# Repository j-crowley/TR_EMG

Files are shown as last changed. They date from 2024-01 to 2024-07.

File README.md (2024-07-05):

# TR_EMG
The Trans-radial EMG (TREMG) is a PCB designed to increase SNR for surface-level EMG electrodes which is then digitized and sent to a controller to drive a robotic prosthetic. This is for individuals with upper limb amputations at the trans-radial level. It enables users to regain dexterity and perform a wide range of tasks using a prosthetic hand. This repository includes the final design of the PCB for this project and does not include the code.

# Credits
Credits to the rest of the capstone team, including: ThaneGallo and coop-bennett.

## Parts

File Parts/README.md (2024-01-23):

# How to import
https://www.snapeda.com/about/import/#KiCad6

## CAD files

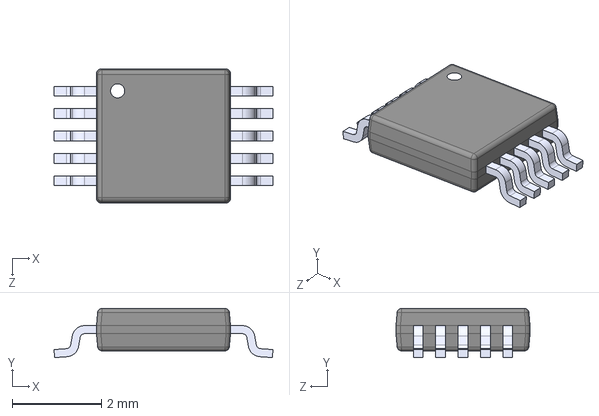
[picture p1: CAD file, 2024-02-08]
Parts/footprints/ADS1115IDGSR.step
4.90 x 1.10 x 3.00 mm

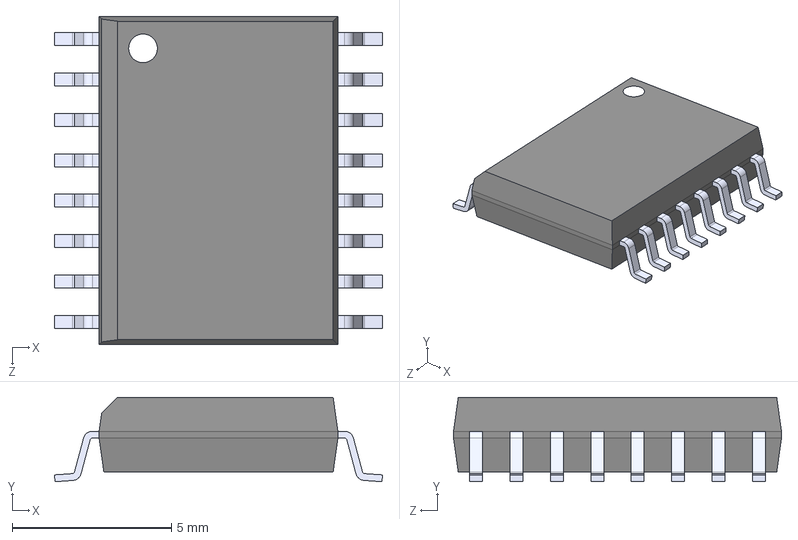
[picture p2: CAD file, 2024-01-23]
Parts/symbols/INA115BU/INA115BU.step
10.3 x 2.65 x 10.3 mm

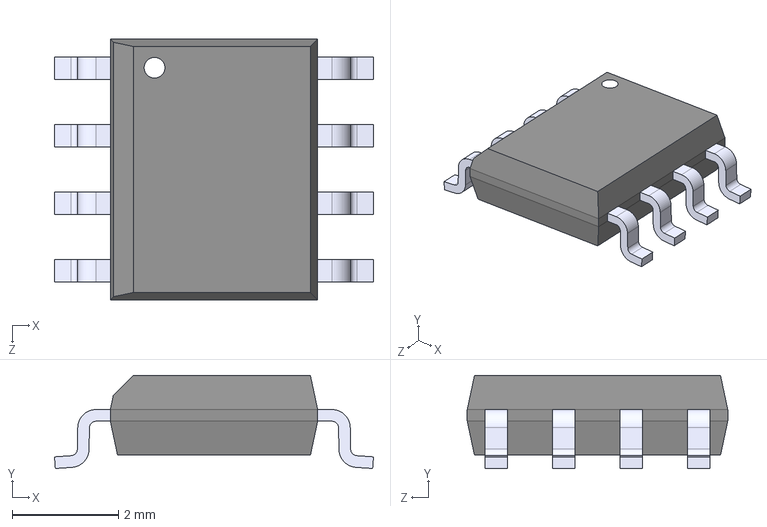
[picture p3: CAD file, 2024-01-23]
Parts/symbols/LM2904DR/LM2904DR.step
6.00 x 1.75 x 4.90 mm

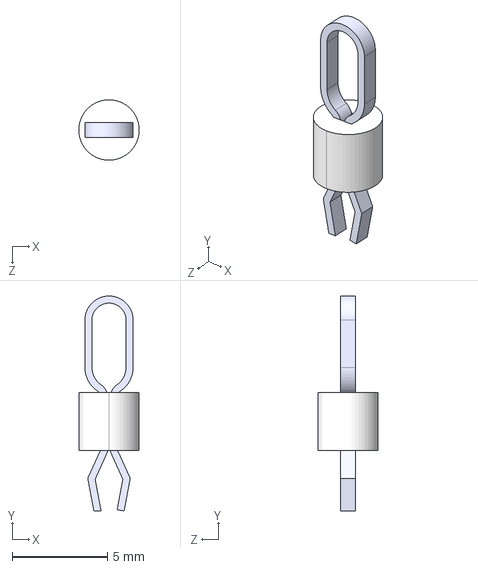
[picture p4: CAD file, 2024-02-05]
Parts/footprints/5012.step
3.17 x 11.3 x 3.17 mm

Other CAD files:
Parts/footprints/INA115BU.step
Parts/footprints/LM2904DR.step

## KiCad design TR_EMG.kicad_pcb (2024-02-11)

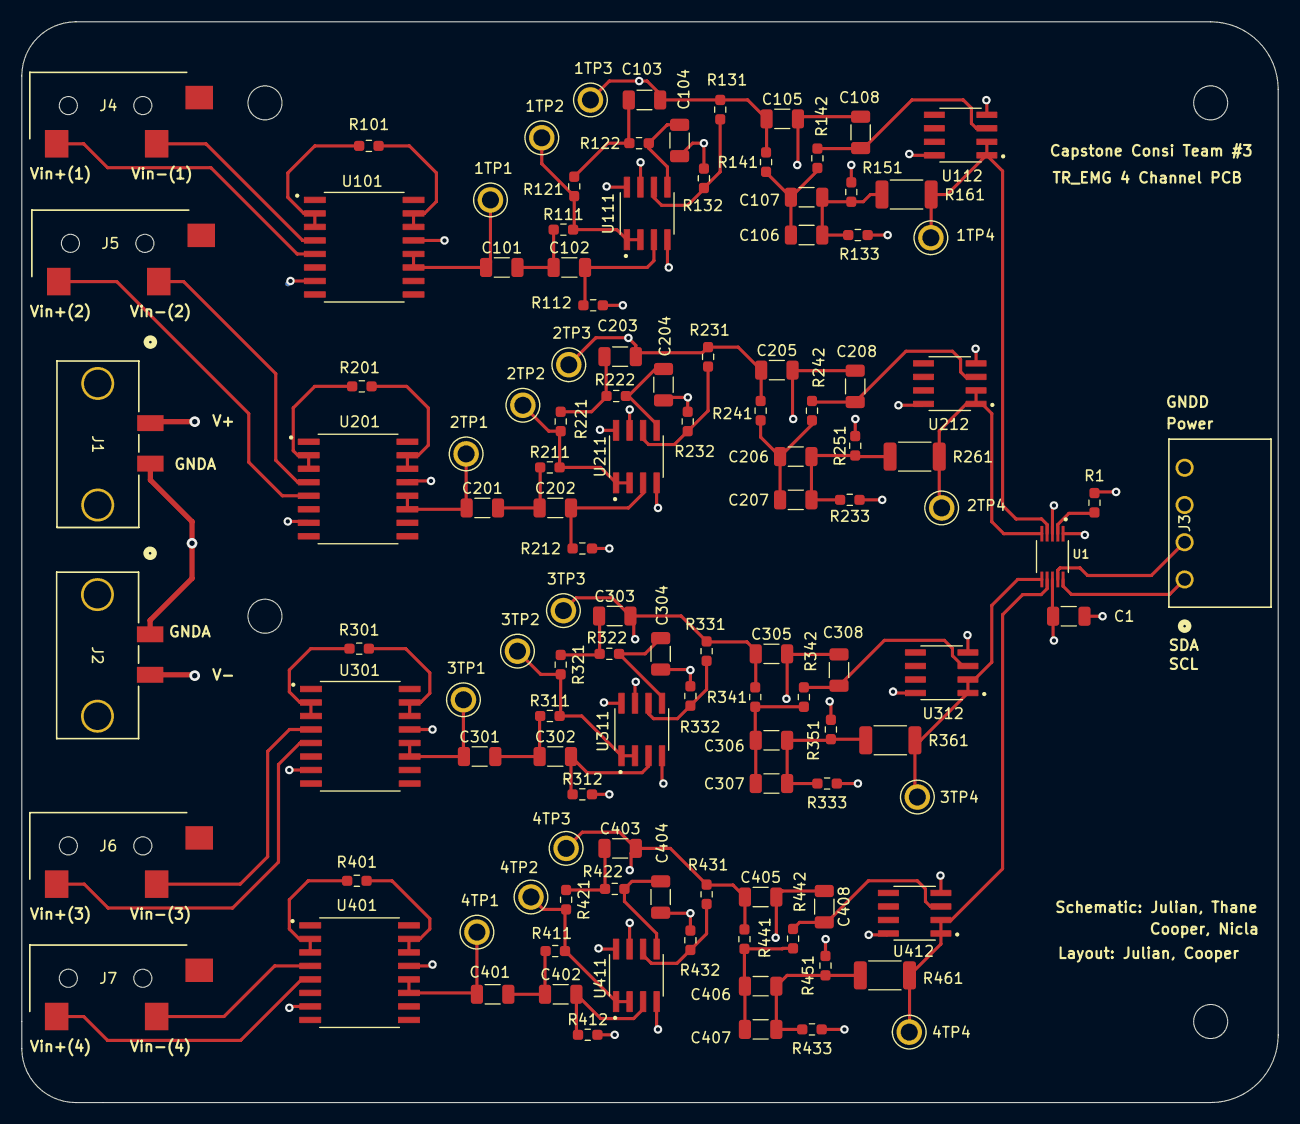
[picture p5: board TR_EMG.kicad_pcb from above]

Board: 4 copper layers, 118.1 x 101.6 mm, 118 parts (0 on the bottom side), 76 nets.

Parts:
1TP1, 1TP2, 1TP3, 1TP4, 2TP1, 2TP2, 2TP3, 2TP4, 3TP1, 3TP2, 3TP3, 3TP4, 4TP1, 4TP2, 4TP3, 4TP4: 5012; TP_5012
C1: 0.1 u; C_1206_3216Metric
C101, C102, C103, C104, C105, C106, C107, C108, C201, C202, C203, C204, C205, C206, C207, C208, C301, C302, C303, C304, C305, C306, C307, C308, C401, C402, C403, C404, C405, C406, C407, C408: 0.1u; C_1206_3216Metric
J1, J2: 1727230; CONN_1727230_PXC
J3: 1844236; CONN_1844236_PXC
J4, J5, J6, J7: MJ-3523-SMT-TR; CONN_MJ-3523_CUD_CtYrd
R1, R131, R132, R231, R232, R331, R332, R431, R432: 1k; R_0603_1608Metric_Pad0.98x0.95mm_HandSolder
R101, R201, R301, R401: 100; R_0603_1608Metric_Pad0.98x0.95mm_HandSolder
R111, R112, R211, R212, R311, R312, R411, R412: 330k; R_0603_1608Metric_Pad0.98x0.95mm_HandSolder
R121, R122, R221, R222, R321, R322, R421, R422: 3.3k; R_0603_1608Metric_Pad0.98x0.95mm_HandSolder
R133, R233, R333, R433: 100k; R_0603_1608Metric_Pad0.98x0.95mm_HandSolder
R141, R142, R241, R242, R341, R342, R441, R442: 26.7k; R_0603_1608Metric_Pad0.98x0.95mm_HandSolder
R151, R251, R351, R451: 13k; R_0603_1608Metric_Pad0.98x0.95mm_HandSolder
R161, R261, R361, R461: 150; R_2010_5025Metric
U1: ADS1115IDGSR; ADS-SOP50P490X110-10N
U101, U201, U301, U401: INA115BU; INA-SOIC127P1030X265-16N
U111, U112, U211, U212, U311, U312, U411, U412: LT1169CS8-PBF; LT-SOIC127P599X175-8N

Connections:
/ADC/AIN0: 1TP4.TP, R161.2, U1.4 (AIN0), U112.1 (OUTA), U112.2 (-INA)
/ADC/AIN1: 2TP4.TP, R261.2, U1.5 (AIN1), U212.1 (OUTA), U212.2 (-INA)
/ADC/AIN2: 3TP4.TP, R361.2, U1.6 (AIN2), U312.1 (OUTA), U312.2 (-INA)
/ADC/AIN3: 4TP4.TP, R461.2, U1.7 (AIN3), U412.1 (OUTA), U412.2 (-INA)
/ADC/Power: C1.2, J3.3, R1.1, U1.8 (VDD)
/ADC/SCL: J3.1, U1.10 (SCL)
/ADC/SDA: J3.2, U1.9 (SDA)
/Filter1/2nd Band Pass Filter (5 - 500 Hz)/Vin: 1TP1.TP, C101.1, U101.11 (VO), U101.12 (FB)
/Filter1/2nd Band Pass Filter (5 - 500 Hz)/Vout: 1TP3.TP, C103.2, C105.1, R131.2, R141.1, U111.7 (OUTB)
/Filter2/2nd Band Pass Filter (5 - 500 Hz)/Vin: 2TP1.TP, C201.1, U201.11 (VO), U201.12 (FB)
/Filter2/2nd Band Pass Filter (5 - 500 Hz)/Vout: 2TP3.TP, C203.2, C205.1, R231.2, R241.1, U211.7 (OUTB)
/Filter3/2nd Band Pass Filter (5 - 500 Hz)/Vin: 3TP1.TP, C301.1, U301.11 (VO), U301.12 (FB)
/Filter3/2nd Band Pass Filter (5 - 500 Hz)/Vout: 3TP3.TP, C303.2, C305.1, R331.2, R341.1, U311.7 (OUTB)
/Filter4/2nd Band Pass Filter (5 - 500 Hz)/Vin: 4TP1.TP, C401.1, U401.11 (VO), U401.12 (FB)
/Filter4/2nd Band Pass Filter (5 - 500 Hz)/Vout: 4TP3.TP, C403.2, C405.1, R431.2, R441.1, U411.7 (OUTB)
GNDA: C104.2, C204.2, C304.2, C404.2, J1.2, J2.1, R112.2, R132.2, R133.1, R212.2, R232.2, R233.1, R312.2, R332.2, R333.1, R412.2, R432.2, R433.1
GNDD: C1.1, J3.4, U1.1 (ADDR), U1.3 (GND)
unnamed: C101.2, C102.1, R111.1
unnamed: C103.1, R121.1, R122.1
unnamed: C105.2, C108.1, R151.2
unnamed: C106.1, C107.1, R133.2, R151.1, R161.1
unnamed: C106.2, C107.2, R141.2, R142.1
unnamed: C201.2, C202.1, R211.1
unnamed: C203.1, R221.1, R222.1
unnamed: C205.2, C208.1, R251.2
unnamed: C206.1, C207.1, R233.2, R251.1, R261.1
unnamed: C206.2, C207.2, R241.2, R242.1
unnamed: C301.2, C302.1, R311.1
unnamed: C303.1, R321.1, R322.1
unnamed: C305.2, C308.1, R351.2
unnamed: C306.1, C307.1, R333.2, R351.1, R361.1
unnamed: C306.2, C307.2, R341.2, R342.1
unnamed: C401.2, C402.1, R411.1
unnamed: C403.1, R421.1, R422.1
unnamed: C405.2, C408.1, R451.2
unnamed: C406.1, C407.1, R433.2, R451.1, R461.1
unnamed: C406.2, C407.2, R441.2, R442.1
unnamed: R1.2, U1.2 (ALERT/RDY)
unnamed: R101.1, U101.2 (G_SEN1), U101.3 (RG)
unnamed: R101.2, U101.14 (RG__1), U101.15 (G_SEN2)
unnamed: C102.2, R112.1, U111.3 (+INA)
unnamed: C104.1, R122.2, U111.5 (+INB)
unnamed: 1TP2.TP, R111.2, R121.2, U111.1 (OUTA), U111.2 (-INA)
unnamed: R131.1, R132.1, U111.6 (-INB)
unnamed: C108.2, R142.2, U112.3 (+INA)
unnamed: R201.1, U201.2 (G_SEN1), U201.3 (RG)
unnamed: R201.2, U201.14 (RG__1), U201.15 (G_SEN2)
unnamed: C202.2, R212.1, U211.3 (+INA)
unnamed: C204.1, R222.2, U211.5 (+INB)
unnamed: 2TP2.TP, R211.2, R221.2, U211.1 (OUTA), U211.2 (-INA)
unnamed: R231.1, R232.1, U211.6 (-INB)
unnamed: C208.2, R242.2, U212.3 (+INA)
unnamed: R301.1, U301.2 (G_SEN1), U301.3 (RG)
unnamed: R301.2, U301.14 (RG__1), U301.15 (G_SEN2)
unnamed: C302.2, R312.1, U311.3 (+INA)
unnamed: C304.1, R322.2, U311.5 (+INB)
unnamed: 3TP2.TP, R311.2, R321.2, U311.1 (OUTA), U311.2 (-INA)
unnamed: R331.1, R332.1, U311.6 (-INB)
unnamed: C308.2, R342.2, U312.3 (+INA)
unnamed: R401.1, U401.2 (G_SEN1), U401.3 (RG)
unnamed: R401.2, U401.14 (RG__1), U401.15 (G_SEN2)
unnamed: C402.2, R412.1, U411.3 (+INA)
unnamed: C404.1, R422.2, U411.5 (+INB)
unnamed: 4TP2.TP, R411.2, R421.2, U411.1 (OUTA), U411.2 (-INA)
unnamed: R431.1, R432.1, U411.6 (-INB)
unnamed: C408.2, R442.2, U412.3 (+INA)
V+: J1.1, U101.13 (V+), U111.8 (V+), U112.8 (V+), U201.13 (V+), U211.8 (V+), U212.8 (V+), U301.13 (V+), U311.8 (V+), U312.8 (V+), U401.13 (V+), U411.8 (V+), U412.8 (V+)
V-: J2.2, U101.7 (V-), U111.4 (V-), U112.4 (V-), U201.7 (V-), U211.4 (V-), U212.4 (V-), U301.7 (V-), U311.4 (V-), U312.4 (V-), U401.7 (V-), U411.4 (V-), U412.4 (V-)
Vin+(1): J4.1, U101.5 (VIN+)
Vin+(2): J5.1, U201.5 (VIN+)
Vin+(3): J6.1, U301.5 (VIN+)
Vin+(4): J7.1, U401.5 (VIN+)
Vin-(1): J4.2, U101.4 (VIN-)
Vin-(2): J5.2, U201.4 (VIN-)
Vin-(3): J6.2, U301.4 (VIN-)
Vin-(4): J7.2, U401.4 (VIN-)

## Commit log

2024-01-23 add board, schematic, and project file
    [TR_EMG.kicad_pcb, TR_EMG.kicad_sch]
2024-01-23 Create footprint dir #1
2024-01-23 Create footprint dir
2024-01-23 added 2 op amp chip symbols and footprint #1
    [LM2904DR.step]
2024-01-23 added instrumentation amplifier #1
    [INA115BU.step]
2024-01-24 add schematic
    [TR_EMG.kicad_sch]
2024-01-25 Added Hierarchy to initial design
    Added hierarchy for the 2nd order lowpass and the band stop filter
    [2ndOrderLowPass.kicad_sch, BandStop.kicad_sch, TR_EMG.kicad_sch]
2024-01-26 add more hierarchical sheets for better formating (instru. amp. and HPF)
    [2ndOrderHighPass.kicad_sch, InstrumentationAmplifier.kicad_sch, TR_EMG.kicad_sch]
2024-01-27 band pass and hierarchy update
    merged high pass and low pass and edited the hierarchy accoridngly
    [2ndOrderHighPass.kicad_sch, 2ndOrderLowPass.kicad_sch, BandPass.kicad_sch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]
2024-01-29 ltspice sims for BPF, BSF, and all filters total
2024-01-30 redone notch filter and minor tweaks to bandpass filter
2024-01-31 added new filter sims, and tweaked components for notch and bandpass filter and circuits for both as well
    [2ndOrderLowPass.kicad_sch, NotchFilter.kicad_sch, TR_EMG.kicad_sch]
2024-02-01 add ADC block
    [TR_EMG.kicad_sch, adc.kicad_sch]
2024-02-03 swapped lpf and hpf in bandpass filter and added testpoints on various filter circuits
    [2ndOrderLowPass.kicad_sch, 5012.step, InstrumentationAmplifier.kicad_sch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]
2024-02-06 Filter abstraction and Input output connectors
    Abstracted filters so there are 4 signal paths to go to ADC. Added input and output connectors.
    [2ndOrderLowPass.kicad_sch, Filter1.kicad_sch, InstrumentationAmplifier.kicad_sch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]
2024-02-06 added connectors for electrode inputs and revamped battery connectors
    [2ndOrderLowPass.kicad_sch, InstrumentationAmplifier.kicad_sch, NotchFilter.kicad_sch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]
2024-02-06 removed sda scl pullups, removed electrode connectors to make space for proper connectors later
    [TR_EMG.kicad_sch, adc.kicad_sch]
2024-02-07 added audio jack connectors for emg connections
    [TR_EMG.kicad_sch]
2024-02-07 Reference Designator and Footprint Updates
    Changed almost all reference designators to group similar components by what filter they are a part of and what value they have.
    Need to:
    - Sort symbol data for ADC and OpAmps to correct folders
    - get footprint files for ADC and OpAmps
    [2ndOrderLowPass.kicad_sch, 5012.step, INA115BU.step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]
2024-02-07 updated GND symbols for appropriate seperatiion of analog and digital grounds
    [2ndOrderLowPass.kicad_sch, NotchFilter.kicad_sch, TR_EMG.kicad_sch]
2024-02-07 renamed and relinked footprints with better clarity footprint file names
    [2ndOrderLowPass.kicad_sch, ADS1115IDGSR.step, InstrumentationAmplifier.kicad_sch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]
2024-02-08 final adjustments for power constraints with changed footprint and resistor values on notch filter feedback portion
    [NotchFilter.kicad_sch]
2024-02-08 changed capacitor footprint to match in stock components (0603 to 1206)
    [2ndOrderLowPass.kicad_sch, NotchFilter.kicad_sch, adc.kicad_sch]
2024-02-08 first chunk of pcb layout and schematics mods (no connects on pins and changing global labels to hieracarchical labels), one filtering pcb circuit layed out
    [InstrumentationAmplifier.kicad_sch, NotchFilter.kicad_sch, TR_EMG.kicad_pcb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]
2024-02-08 finished majority of layout, pcb expanded to four copper layers to accomadate power planes
    [TR_EMG.kicad_pcb, TR_EMG.kicad_sch]
2024-02-08 Final touches to silkscreen on pcb, DRC check still needed
    [TR_EMG.kicad_pcb]
2024-02-08 modified footprints and IC silkscreen refereence designators to comply with DRC checks
    [TR_EMG.kicad_pcb]
2024-02-08 DRC check passed, but ADC/ADS footprint needs to be checked for JLCPCB compatability (pads may be too close together)
    [TR_EMG.kicad_pcb]
2024-02-08 Extended ground planes, rerouted some traces into vias. and pushed connectors to edge of board
    [TR_EMG.kicad_pcb]
2024-02-08 ToTheEdge,LCSCNums
    Moved the 3.5mm connectors to the edge and edited their footprint courtyard so no errors. Adjusted the planes so that it bordered 3.5mm connector pads well and didn't go to edge cuts. Added LCSC part numbers to the parts that were in stock.
    [2ndOrderLowPass.kicad_sch, InstrumentationAmplifier.kicad_sch, NotchFilter.kicad_sch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]
2024-02-08 Pushed adc connector to edge of pcb
    [TR_EMG.kicad_pcb]
2024-02-09 nore footprint tweaking to meet DRC requirements
    [TR_EMG.kicad_pcb]
2024-02-09 added mounting holes, board ready for export
    [TR_EMG.kicad_pcb]
